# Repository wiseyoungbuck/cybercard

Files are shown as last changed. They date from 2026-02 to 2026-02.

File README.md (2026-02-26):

# NFC Business Card PCB

Transparent NFC business card for GTC. Credit-card sized (85.6mm x 53.98mm) PCB with an NFC antenna, IC, and decorative copper/silkscreen artwork.

## Viewing the Design

### Open in KiCad 9
1. Open KiCad 9
2. File > Open > select `business_card.kicad_pcb`
3. The file opens directly as a standalone PCB (no schematic/project needed)

### Viewing Layers
- **Front copper (F.Cu)**: Antenna spiral, "The Matthew Effect", "MATT COBURN", neural network motif
- **Front silkscreen (F.SilkS)**: "Applied AI x Security"
- **Back copper (B.Cu)**: IC pads, cap pads, routing traces from antenna vias
- **Back silkscreen (B.SilkS)**: CTA text, NFC icon, contact info, QR placeholder
- Toggle layers on/off in the right sidebar Layers panel

### 3D Viewer
- View > 3D Viewer (or Alt+3) to see a realistic rendering of both sides
- Use middle-mouse to rotate, scroll to zoom
- Press `Z` to flip the board and inspect the back side

### CLI Preview (no GUI needed)
```bash
# Render front side to PNG
kicad-cli pcb export svg business_card.kicad_pcb -o front.svg --layers "F.Cu,F.SilkS,Edge.Cuts"
rsvg-convert front.svg -o front.png -w 1200

# Render back side to PNG (mirrored for correct reading)
kicad-cli pcb export svg business_card.kicad_pcb -o back.svg --layers "B.Cu,B.SilkS,Edge.Cuts" --mirror
rsvg-convert back.svg -o back.png -w 1200

# Run DRC check
kicad-cli pcb drc business_card.kicad_pcb -o drc_report.json --severity-all
```

## Design Overview

### Front Side (F.Cu + F.SilkS)
- **Antenna**: 3-turn rectangular spiral on F.Cu (0.5mm trace, 0.5mm gap, ~1.42uH)
- **Text**: "The Matthew Effect" and "MATT COBURN" in copper, "Applied AI x Security" in silkscreen
- **Neural network motif**: Decorative node-edge graph in copper flanking the text
- **Logo zone**: 10mm x 10mm courtyard placeholder at center-bottom

### Back Side (B.Cu + B.SilkS)
- **IC**: NT3H2111 NFC tag IC in SOT-886 package (U1)
- **Capacitor**: 47pF 0402 tuning cap (C1)
- **CTA**: "TAP YOUR PHONE TO TALK TO MY AI" with NFC contactless icon
- **Contact info**: Name, title, email in silkscreen
- **QR code**: Placeholder — replace with actual QR for `https://mattcoburn.ai/card`

### Antenna Design
- Target inductance: ~1.42uH (13.56MHz resonance with ~97pF total capacitance)
- Modified Wheeler formula: 3 turns, 0.5mm trace, 0.5mm gap
- 3mm inset from board edge
- Two vias connect antenna ends to IC on back side

## DRC Status

3 warnings (all non-critical):
- Silkscreen clipped by solder mask (U1 reference label — cosmetic)
- Missing footprint libraries `NFC` and `Passive` (custom footprints defined inline)

0 errors. 0 unconnected pads.

## TODO Before Fabrication

1. **QR Code** ([THE-183](https://linear.app/thedolist/issue/THE-183/add-qr-code-to-nfc-business-card-pcb)): Replace the placeholder rectangle with actual QR code modules.
2. **Logo**: Add Tangible AI logo in the courtyard zone on F.Cu or F.SilkS.
3. **Visual review**: Open in KiCad 3D viewer to inspect both sides.
4. **Verify antenna**: Consider NFC simulation or test with prototype.
5. **Export Gerbers**: File > Fabrication Outputs > Gerbers for JLCPCB upload.

## Manufacturing

Target: JLCPCB Transparent FPC (prototype on FR-4)

| Parameter | Value |
|---|---|
| Board size | 85.6mm x 53.98mm |
| Layers | 2 (F.Cu + B.Cu) |
| Trace width | 0.5mm (antenna), 0.3mm (routing), 0.2mm (motif) |
| Via | 0.6mm pad / 0.3mm drill |
| Corner radius | 3.18mm |

## Components

| Ref | Value | Package | Description |
|-----|---|---|---|
| U1 | NT3H2111 | SOT-886 | NFC tag IC |
| C1 | 47pF | 0402 | Tuning capacitor |

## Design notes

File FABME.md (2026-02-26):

# Fabrication & Assembly Guide

## Parts List

| Part | Value | Package | LCSC # | Qty | ~Cost |
|---|---|---|---|-----|---|
| U1 | NXP NT3H2111W0FHKH | SOT-886 | C710403 | 1 | $0.50 |
| C1 | 47pF C0G 0402 | 0402 | C1552 | 1 | $0.01 |

## Step 1: Export Gerbers

1. Open `business_card.kicad_pcb` in KiCad 9
2. File > Fabrication Outputs > Gerbers (.gbr)
3. Select all copper + mask + silkscreen + Edge.Cuts layers
4. Check "Use Protel filename extensions" for JLCPCB compatibility
5. Generate drill files (Excellon format) in the same output directory
6. Zip all `.gbr` + `.drl` files together

## Step 2: Order PCBs from JLCPCB

1. Go to [jlcpcb.com](https://www.jlcpcb.com) > Order Now
2. Upload the Gerber zip
3. Settings:
   - **Base Material**: FR-4 (prototype) or Flex (FPC) for transparent
   - **Layers**: 2
   - **PCB Thickness**: 0.8mm (FR-4) or 0.2mm (FPC)
   - **Surface Finish**: ENIG (gold traces)
   - **Solder Mask**: None or transparent (for the clear look)
   - **Silkscreen**: White
   - **PCB Color**: N/A if no mask, otherwise clear/transparent
4. For transparent cards specifically, select "Transparent FPC" if available
5. Quantity: 5 minimum (they're cheap — order 10+)

## Step 3: Order SMT Assembly (Recommended)

Hand-soldering a SOT-886 (1mm flip-chip) is brutal. Let JLCPCB do it.

1. On the same JLCPCB order, toggle "SMT Assembly"
2. Select **Bottom Side** (components are on B.Cu)
3. Upload BOM:
   ```
   Comment,Designator,Footprint,LCSC
   NT3H2111W0FHKH,U1,SOT-886,C710403
   47pF,C1,0402,C1552
   ```
4. Upload pick-and-place (CPL) file — export from KiCad:
   File > Fabrication Outputs > Component Placement (.pos)
5. Confirm placements in JLCPCB's visual preview
6. Review & order

## Step 4: Program the NFC Tag

Once boards arrive with components soldered:

1. Install **NFC Tools** on your phone
   - [Android (Play Store)](https://play.google.com/store/apps/details?id=com.wakdev.wdnfc)
   - [iPhone (App Store)](https://apps.apple.com/app/nfc-tools/id1252962749)
2. Open NFC Tools > **Write** tab
3. **Add a record** > URL > `https://mattcoburn.ai/card`
4. Tap **Write**
5. Hold your phone flat against the card (center of card, over the antenna area)
6. Wait for confirmation buzz/notification
7. Done — the URL is permanently stored until you overwrite it

## Step 5: Test

1. Lock your phone, then tap the card against it
2. Phone should show a notification to open `mattcoburn.ai/card`
3. Test with both Android and iPhone if possible
4. Test reading distance — should work through a phone case at 1-3cm

## Troubleshooting

**Phone doesn't detect the card:**
- Make sure NFC is enabled on the phone
- Try different positions — the phone's NFC reader is usually near the camera
- The antenna may need tuning — try a different value cap (39pF or 56pF)

**Read range is very short (<1cm):**
- Antenna inductance may be off — the 47pF cap assumes ~1.42uH
- Try swapping C1 to 39pF (higher inductance tolerance) or 56pF (lower)
- FR-4 substrate has higher dielectric losses than PET — range will improve on transparent FPC

**NFC Tools can't write:**
- NT3H2111 may have write protection enabled — use NFC Tools to check/reset
- Make sure you're writing NDEF format, not raw memory

## Cost Estimate (10 cards)

| Item | Cost |
|---|---|
| PCBs (10x, FR-4, ENIG) | ~$15 |
| SMT Assembly | ~$8 setup + $1/board |
| Components (NT3H2111 + cap) | ~$5 total |
| Shipping | ~$10 |
| **Total** | **~$40 for 10 cards** |

Transparent FPC is more expensive (~$50-80 for the boards alone), so prototype on FR-4 first.

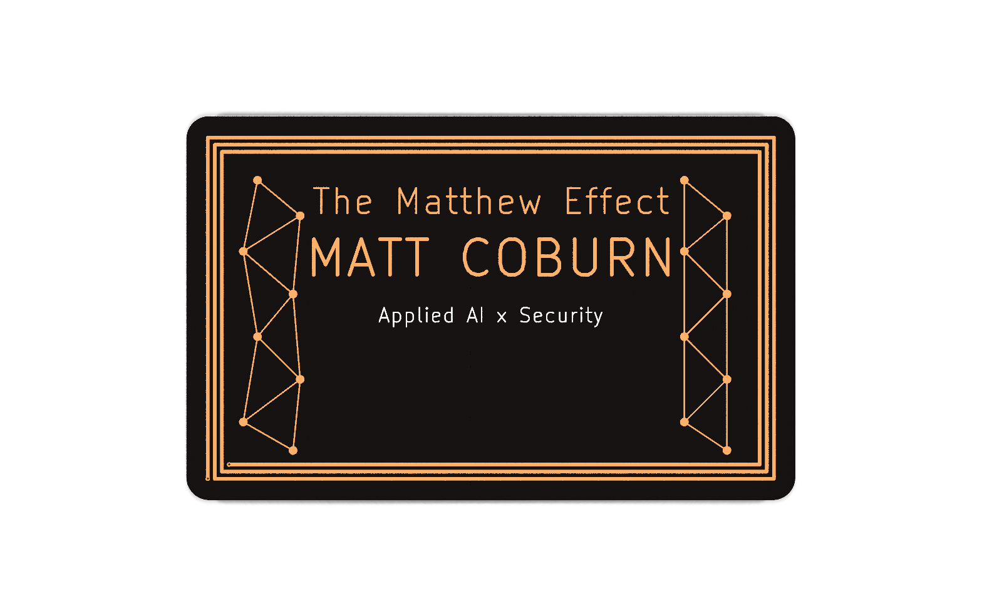
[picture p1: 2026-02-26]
render_clear_top.png

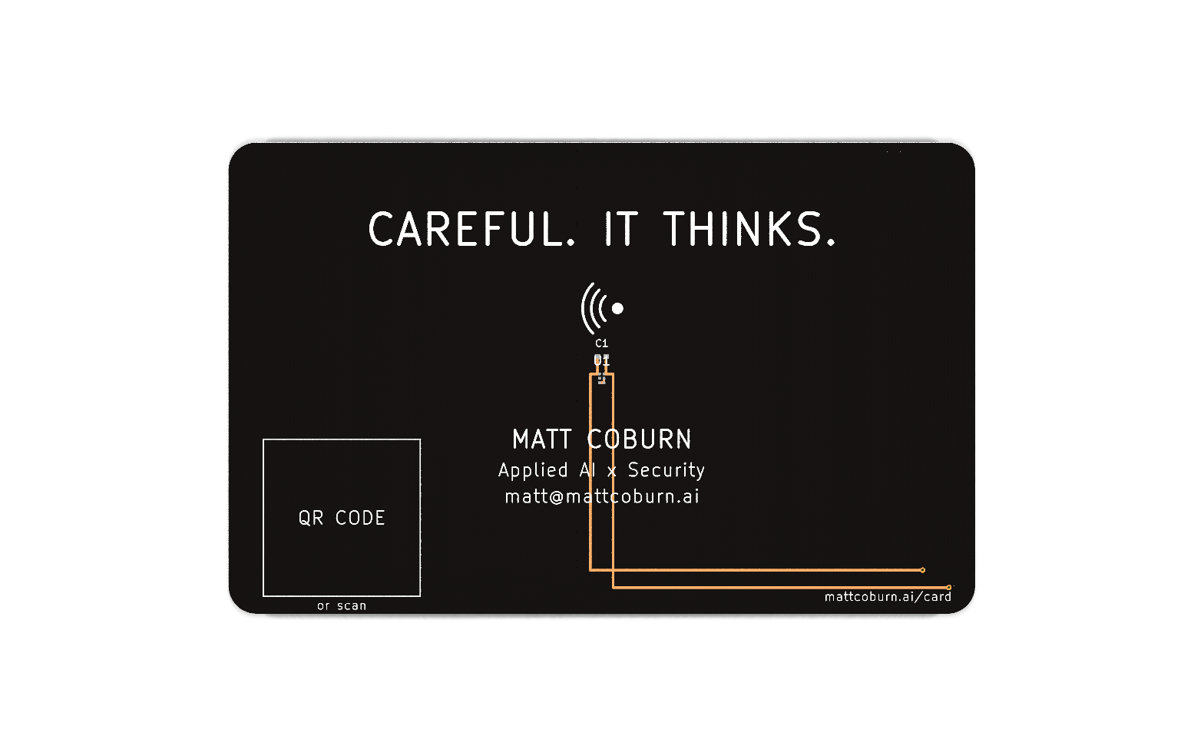
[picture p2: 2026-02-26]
render_bottom.png

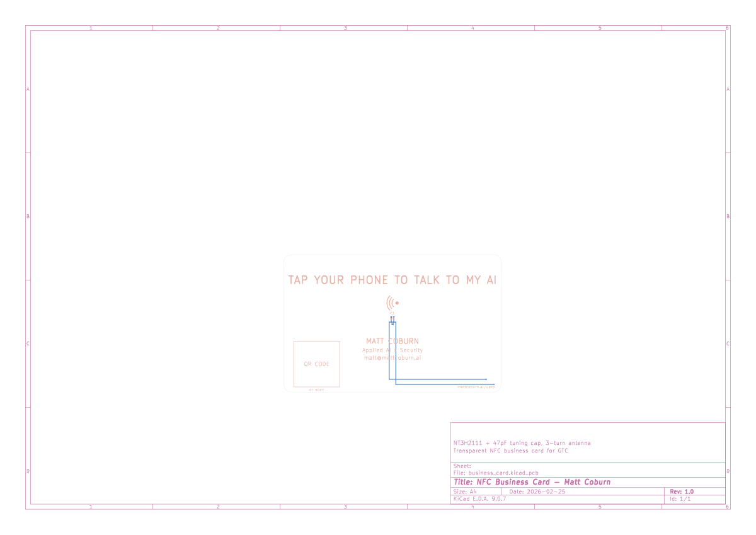
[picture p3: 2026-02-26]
preview_back_2d.png

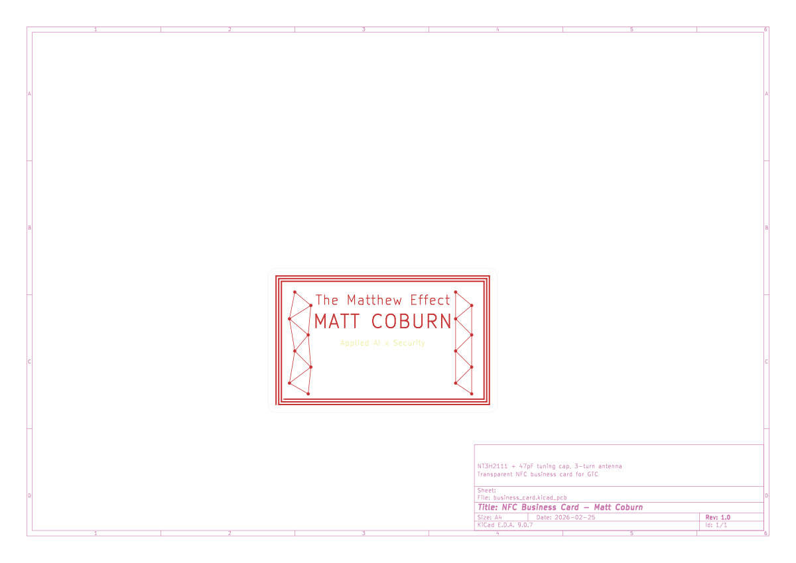
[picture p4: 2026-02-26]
preview_front_2d.png

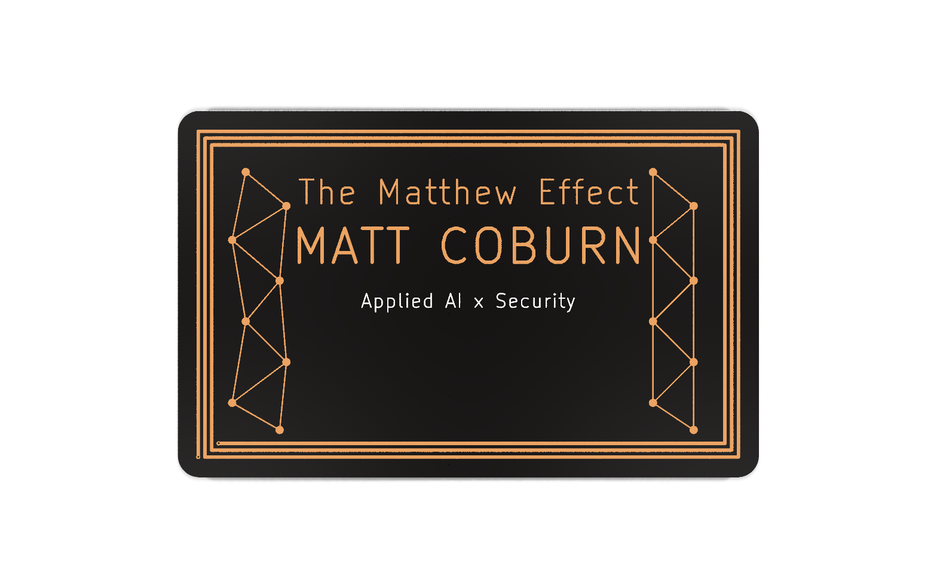
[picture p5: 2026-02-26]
render_top.png

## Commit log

2026-02-26 feat: generate NFC business card PCB design (THE-179)
    Complete KiCad 9 PCB design for transparent NFC business card:
    - 85.6x53.98mm board with 3.18mm corner radius (ISO credit card)
    - 3-turn rectangular antenna spiral on F.Cu (~1.42uH, 13.56MHz)
    - NT3H2111 SOT-886 NFC IC + 47pF 0402 tuning cap on B.Cu
    - Copper text ("The Matthew Effect", "MATT COBURN") on F.Cu
    - Neural network motif (16 nodes, 26 edges) on F.Cu
    - Back silkscreen: CTA, NFC icon, contact info, QR placeholder
    - DRC clean (0 errors, 3 cosmetic warnings)
    QR code generation split to THE-183.
    [business_card.kicad_pcb]
2026-02-26 feat: update CTA to "CAREFUL. IT THINKS." and set ENIG copper finish
    - Replace "TAP YOUR PHONE TO TALK TO MY AI" with "CAREFUL. IT THINKS."
    - Larger 3.5mm bold text for impact
    - Set copper finish to ENIG (gold) for transparent card aesthetic
    - Set solder mask to transparent for clear substrate rendering
    [business_card.kicad_pcb]
2026-02-26 docs: add step-by-step fabrication guide (FABME.md)
    Covers Gerber export, JLCPCB ordering, SMT assembly,
    NFC programming with phone app, testing, and troubleshooting.
2026-02-27 feat: embed real QR code for mattcoburn.ai/card on back silkscreen (THE-183)
    Replace placeholder rectangle and "QR CODE" label with 332 filled
    silkscreen modules encoding https://mattcoburn.ai/card (QR version 2,
    error correction M, 25x25 matrix, 0.72mm module size). Mirrored
    horizontally for correct back-side scanning. DRC clean.
    [business_card.kicad_pcb]
